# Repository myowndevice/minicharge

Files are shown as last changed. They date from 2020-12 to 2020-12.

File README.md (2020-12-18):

## Мини зарядное устройство для литиевого аккумулятора

Это мини устройство позволяет зарядить один литиевый аккумулятор от micro USB разъёма. Несложная пайка. Позволяет познакомиться с основами микроэлектроники, научиться паять SMD компоненты. Это устройство принесёт вам большую пользу как дома, так и в приборостроении.
С его помощью можно восстановить аккумулятор «ушедший» в глубокий разряд, зарядить запасной аккумулятор сотового телефона, зарядить аккумуляторы таблетки LIR2030 и аналогичные, а также любой аккумулятор в широко распространнёном размере 18650 или любом другом.

Основные параметры:
- Ток заряда — 40мА, 120мА, 600мА
- Компактный размер
- Работа с любыми аккумуляторами типа Li-pol, Li-ion (напряжение заряда 4.2В)
- Питание по проводу microusb от компьютера или любого зарядного устройства телефона
- Защита от переплюсовки аккумулятора
- Светодиодный индикатор окончания заряда
    
Данный репозитарий содержит все необходимые файлы для изготовления зарядного устройства.Если вы будете скачивать файлы через web не забудьте скачать общую папку Kicadlib.

Ознакомится со схемой и подробным описанием мини зарядного устройства и порядка сборки можно, [прочитав эту подробную статью](http://myowndevice.ru/index.php/pribory/instrumenty-i-izmeritelnye-pribory/item/51-mini-zaryadnoe-ustrojstvo)

Также [здесь](http://myowndevice.ru) вы найдете подробное описание как сделать другие приборы, много теории о том, как их делать, методику изготовления печатных плат и много другого.

Изучай микроконтроллеры, делай платы дома, разрабатывай электронику сам!

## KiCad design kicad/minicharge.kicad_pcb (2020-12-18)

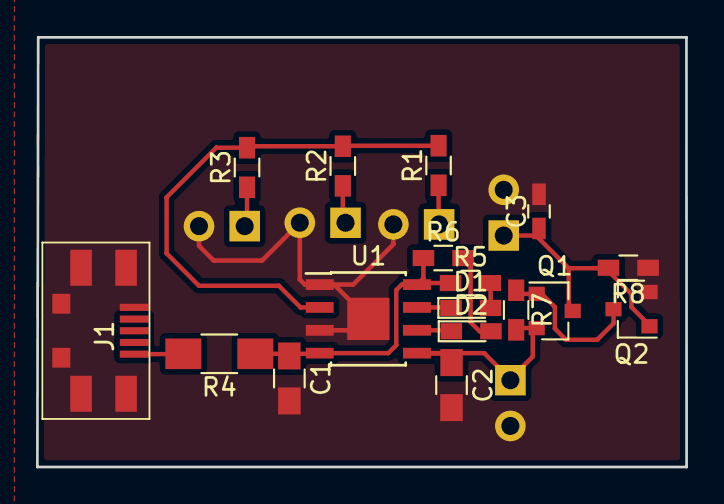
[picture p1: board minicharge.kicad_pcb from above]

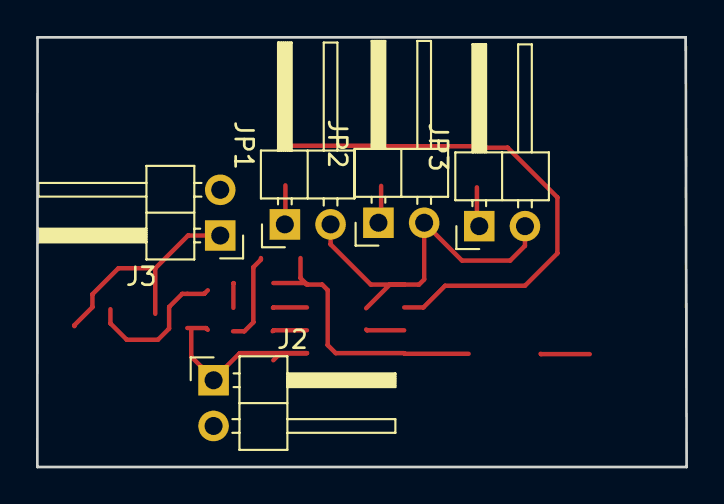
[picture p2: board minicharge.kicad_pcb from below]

Board: 2 copper layers, 36.1 x 23.9 mm, 22 parts (5 on the bottom side), 14 nets.

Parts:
C1, C2: 10u; C_0805_HandSoldering
C3: 100n; C_0603_HandSoldering
D1, D2: LED; LED_0603_HandSoldering
J1: USB_OTG; usb5s_flip
J2: BAT2; Pin_Header_Angled_1x02_Pitch2.54mm
J3: BAT; Pin_Header_Angled_1x02_Pitch2.54mm
JP1, JP2, JP3: Jumper_NO_Small; Pin_Header_Angled_1x02_Pitch2.54mm
Q1: IRLML6402; SOT-23
Q2: irlml2502; SOT-23
R1: 30k; R_0603_HandSoldering
R2: 10k; R_0603_HandSoldering
R3: 2k; R_0603_HandSoldering
R4: 0R5; R_1206_HandSoldering
R5, R6: 1k; R_0603_HandSoldering
R7, R8: 100k; R_0603_HandSoldering
U1: TP4056; SOIC-8-1EP_3.9x4.9mm_Pitch1.27mm

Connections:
/prog: R1.2, R2.2, R3.2, U1.2
/vin: C1.1, R4.1, R5.1, R6.1, U1.4, U1.8
GND: C1.2, C2.2, C3.2, J1.5, J2.2, J3.2, JP1.2, JP2.2, JP3.2, Q2.2, R8.1, U1.1, U1.3, U1.9
unnamed: C2.1, J2.1, Q1.2, R7.2, U1.5
unnamed: C3.1, J3.1, Q1.3, Q2.1, R8.2
unnamed: D1.1, U1.7
unnamed: D1.2, R5.2
unnamed: D2.1, U1.6
unnamed: D2.2, R6.2
unnamed: J1.1, R4.2
unnamed: JP1.1, R1.1
unnamed: JP2.1, R2.1
unnamed: JP3.1, R3.1
unnamed: Q1.1, Q2.3, R7.1
